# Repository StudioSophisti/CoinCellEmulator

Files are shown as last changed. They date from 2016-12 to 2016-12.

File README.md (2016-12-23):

# Coin Cell Emulator

Tired of wasting Coin Cell batteries? With this CR2032 Coin Cell emulator you have an infintely charged battery, connected using USB mini. At Studio Sophisti (http://www.studiosophisti.nl/) we use this PCB intensively in order to reduce our battery consumption.

This product consists out of 2 PCB's that are stacked. If you produce them at 1.6mm thickness, they match exactly the CR2032 size.

### Partlist

- 2 1uF capacitor: Farnell 2496916
- 1 LP3985IM5-3.0 LDO: Farnell 1469153
- 1 MOLEX 67503-1020 Mini USB: Farnell 1125348

### PCB Preview

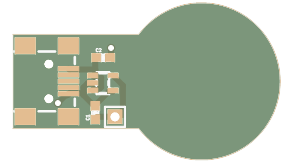
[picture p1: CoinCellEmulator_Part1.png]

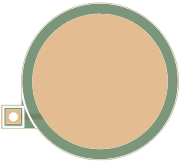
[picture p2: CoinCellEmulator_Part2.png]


Generated with GerberTools from ThisIsNotRocketScience (https://github.com/ThisIsNotRocketScience/GerberTools), thanks Stijn!

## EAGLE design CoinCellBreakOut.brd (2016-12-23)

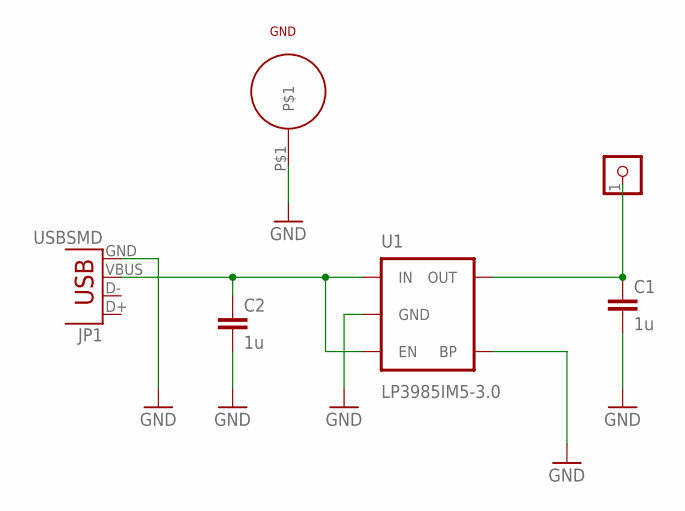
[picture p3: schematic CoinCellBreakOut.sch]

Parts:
3V: CON_HEADER_1X01-PTH_10_17; M1X2_10_17
C1, C2: 1u; 0603-CAP
GND: COIN_CELL_CONTACT
JP1: USBSMD; USB-MINIB
U1: LP3985IM5-3.0; SOT23-5

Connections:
GND: C1.2, C2.2, GND.P$1, JP1.GND, U1.2 (GND), U1.4 (BP)
unnamed: C2.1, JP1.VBUS, U1.1 (IN), U1.3 (EN)
unnamed: 3V.1, C1.1, U1.5 (OUT)

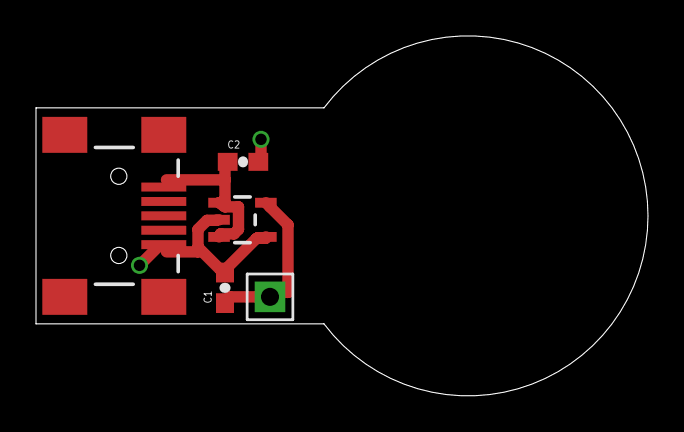
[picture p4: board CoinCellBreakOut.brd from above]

Board: 2 copper layers, 34.0 x 20.0 mm, 6 parts (1 on the bottom side), 3 nets.

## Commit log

2016-12-23 added eagle files
    [CoinCellBreakOut.GBL, CoinCellBreakOut.GBO, CoinCellBreakOut.GBP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]
2016-12-23 fixed tracks near usb connector
    [CoinCellBreakOut.brd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]

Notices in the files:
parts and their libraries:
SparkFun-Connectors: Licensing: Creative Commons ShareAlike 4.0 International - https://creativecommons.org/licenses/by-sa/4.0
